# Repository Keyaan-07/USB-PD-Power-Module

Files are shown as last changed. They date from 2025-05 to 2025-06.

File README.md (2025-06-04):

# USB-PD-Power-Supply
Sometimes it happens that when playing with electronics, we need more than 5V or 9V. USB PD Power Supply Solves this issue.  
By using USB PD Protocol, it can negotiate more than 5V from the USB PD charger. It can give voltage outputs as supported by the PD charger from 5V to 20V and it also supports the new USB PPS protocol which allows us set the voltage according to our own needs. For Example, if some device needs 18V, PPS can do the task and it could supply voltage.  

USB PD Power Supply can use both PD and PPS to cupply voltage. The microcontroller is the OG RP2040, which communications with the AP33772SDKZ USB PD negotiator IC to negotiate voltage levels. The Voltage and max current settings are controllable using the two rotary encoders present on the PCB.  

## How the heck do you assemble this thing?
First of all, you start with the gerber and upload it to your desired pcb manufacturer, I am gonna use [PCB Power](https://pcbpower.com). Now you order the PCB and all the components, and you wait, after they arrive, you cook(assemble) the PCB. Then what you do is that you upload the code and start using, 3D printed case is optional but you could download the files for that too! Flash firmware(firmware to come in a few days) on RP2040 using thonny or other software and boom your [USB-PD-Power-supply](https://github.com/Keyaan-07/USB-PD-Power-Supply/) is ready

## Why I chose to make this Project
I chose to make this project mainly because of the power issues i face. A few days ago, I wanted to power a coil for an electromagnet, i was not able to power it because of power supply from the Power bank (5V) was not enough, so i had the idea of making this because my dad's phone has a USB PD Charger so i could use that charger to power electronics that require higher voltage. That type of a project would be too simple, so i also added two rotary encoders and make a dedicated power supply. 

# Images
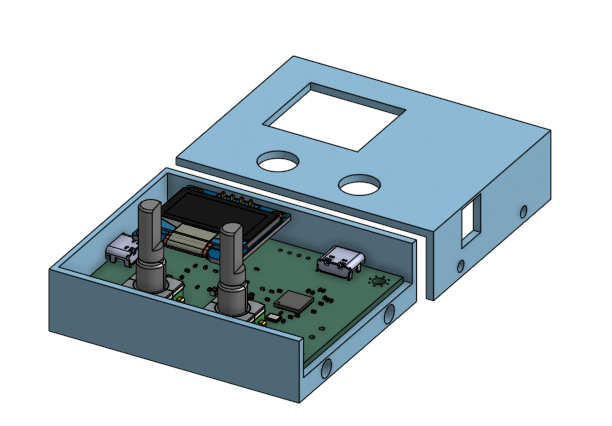
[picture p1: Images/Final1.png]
     
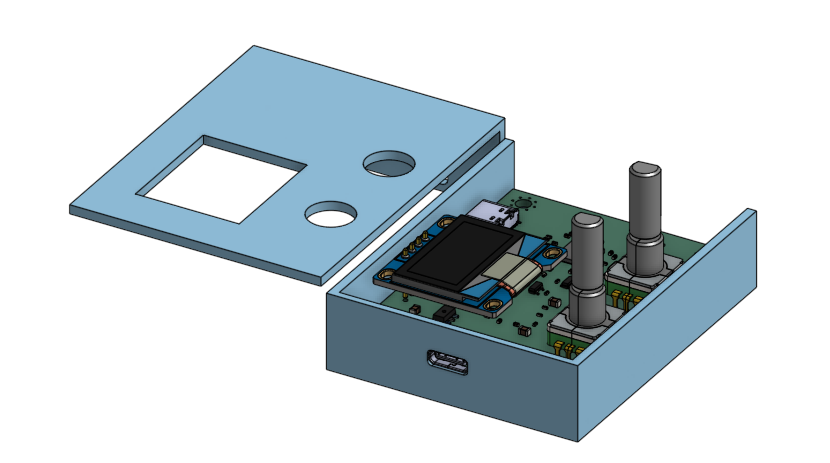
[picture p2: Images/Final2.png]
 
<br>

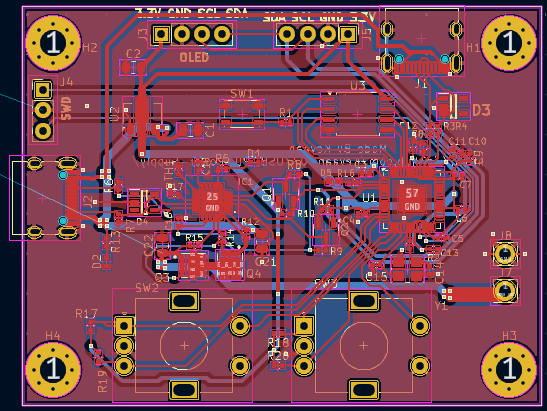
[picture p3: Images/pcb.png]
  

<br>  

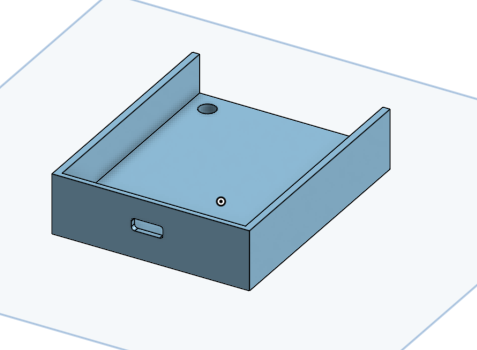
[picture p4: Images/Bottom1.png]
  
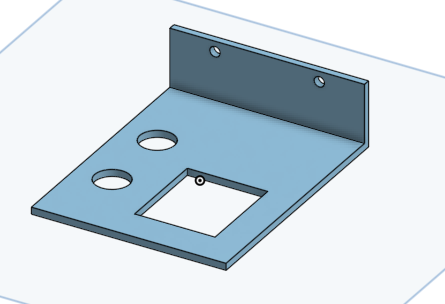
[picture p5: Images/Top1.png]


# BOM - Bill Of All Materials:

| ITEM NAME | ITEM PRICE | FUNCTION | URL |
| --- | --- | --- | --- |
| PCB Manufacturing(5 units) | $29.20 | Main PCB | [https://pcbpower.com](https://pcbpower.com/) |
| PCB Components | $32.12 | All the PCB Components | [https://lcsc.com](https://lcsc.com/) |
| PCB Stencil | $27.25 | Stencil for Assembly of PCB | [https://pcbpower.com](https://pcbpower.com/) |
| OLED and Headers + M3 screws and inserts, Solder Paste | $9.13 | Displays voltage and current levels, assembly body, and solder | https://roboticsdna.in/product/1-3-inch-iic-128x64-oled-display-module-4-pin-blue/ ,  https://roboticsdna.in/product/m3-x-6mm-brass-heat-set-threaded-round-insert-nut-25-pcs/ ,  https://roboticsdna.in/product/m3-6mm-ss-25-pieces/ ,  https://roboticsdna.in/product/2-54mm-1x20-right-angle-female-header-strip-2/ ,   https://roboticsdna.in/product/original-mechanic-30g-solder-paste/ |
| 3d parts | $7.98 | 3d parts | [https://3ding.in/](https://3ding.in/) |
| Total | $105.68 | | |
### Note: There are a few resistors and capacitors, which had very high minimum order quantity(MOQ), about 100 pieces so i had to forcefully include those, which i will be utilising in my next highway projects. And tbh the prices were very less(about $0.002 per piece) so i think it is alright

# PCB Components Breakdown:  

| Id | Designator | MPN | Footprint | DNP | MOQ | Price  | Quantity | Designation | Amount | LCSC Part No. | Supplier and ref |
| -- | --- | --- | --- | --- | --- | --- | --- | --- | --- | --- | --- |
| 1  | Q1,Q2 | BSS138 | SOT-23 | No  | Yes | 0.0571 | 10 | BSS138 | 0.571  | C82045 | https://www.lcsc.com/product-detail/MOSFETs_onsemi-BSS138LT1G_C82045.html?s_z=n_bss138 |
| 2  | C21,C1,C2,C22 | GRM21BR61H106KE43L | C_0805_2012Metric | No  | Yes | 0.0509 | 100 | 10u | 5.09 | C440198 | https://www.lcsc.com/product-detail/Multilayer-Ceramic-Capacitors-MLCC-SMD-SMT_Samsung-Electro-Mechanics-CL21A106KBYQNNE_C2932476.html |
| 3  | R17,R10,R9,R20,R18,R19,R7,R6,R8,R11  | RC0402FR-7W5K1L | R_0402_1005Metric | No  | Yes | 0.0057 | 100 | 5.1k | 0.57 | C278598 | https://www.lcsc.com/product-detail/Chip-Resistor-Surface-Mount_PANASONIC-ERJ2RKF5101X_C278598.html |
| 4  | C14,C15 | GJM1555C1H150FB01D | C_0402_1005Metric | No  | Yes | 0.021  | 20 | 15p | 0.42 | C441742 | https://www.lcsc.com/product-detail/Multilayer-Ceramic-Capacitors-MLCC-SMD-SMT_Murata-Electronics-GJM1555C1H150FB01D_C441742.html |
| 5  | J5 | generic | PinHeader_1x04_P2.54mm_Vertical | Yes | Yes | 0 | 1 | Conn_01x04_Socket_external | 0 | | \- |
| 6  | R2,R1,R5,R16 | ERJPA2F1001X | R_0402_1005Metric | No  | Yes | 0.027  | 20 | 1k | 0.54 | C427241 | https://www.lcsc.com/product-detail/Chip-Resistor-Surface-Mount_PANASONIC-ERJPA2F1001X_C427241.html |
| 7  | Q4,Q3 | AON7672E | TRANS_AONR21307 | No  | No  | 0.7665 | 5 | AON7672E | 3.8325 | C176755 | https://www.lcsc.com/product-detail/MOSFETs_Alpha-Omega-Semicon-AON7262E_C176755.html |
| 8  | C12,C18,C4,C8,C13,C3,C7,C9,C6,C5,C17 | GRM155R61H104JE14D | C_0402_1005Metric | No  | Yes | 0.0074 | 100 | 100n | 0.74 | C426067 | https://www.lcsc.com/product-detail/Multilayer-Ceramic-Capacitors-MLCC-SMD-SMT_Murata-Electronics-GRM155R61H104JE14D_C426067.html |
| 9  | J1 | TYPE-C16PIN | USB_C_Receptacle_XKB_U262-16XN-4BVC11 | No  | Yes | 0.0656 | 10 | USB_C_Receptacle_USB2.0_14P_RP2040 | 0.656  | C393939 | https://www.lcsc.com/product-detail/USB-Connectors_SHOU-HAN-TYPE-C16PIN_C393939.html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 |
| 10 | C10,C11,C16 | GRM155R61H105KE05D | C_0402_1005Metric | No  | Yes | 0.0247 | 20 | 1u | 0.494  | C1518208 | https://www.lcsc.com/product-detail/Multilayer-Ceramic-Capacitors-MLCC-SMD-SMT_Murata-Electronics-GRM155R61H105KE05D_C1518208.html |
| 11 | J4 | generic | PinHeader_1x03_P2.54mm_Vertical | Yes | Yes | 0 | 1 | Conn_01x03_Pin_SWD | 0 | | \- |
| 12 | R13 | RCS040210K0FKED | R_0402_1005Metric | No  | Yes | 0.0278 | 50 | 10k | 1.39 | C3020235 | https://www.lcsc.com/product-detail/Chip-Resistor-Surface-Mount_Vishay-Intertech-RCS040210K0FKED_C3020235.html |
| 13 | D1,D2 | 16-213/GHC-YR1S1N/3T | LED_0402_1005Metric | No  | Yes | 0.0526 | 20 | LED | 1.052  | C2980183 | https://www.lcsc.com/product-detail/LED-Indication-Discrete_Everlight-Elec-16-213-GHC-YR1S1N-3T_C2980183.html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 |
| 14 | U1 | RP2040 | QFN-56-1EP_7x7mm_P0.4mm_EP3.2x3.2mm | No  | No  | 1.1274 | 2 | RP2040 | 2.2548 | C2040 | https://www.lcsc.com/product-detail/Microcontrollers-MCU-MPU-SOC_Raspberry-Pi-RP2040_C2040.html?s_z=n_rp2040 |
| 15 | J2 | TYPE-C16PIN | USB_C_Receptacle_XKB_U262-16XN-4BVC11 | No  | No  | 0.0656 | 0 | USB_C_Receptacle_USB2.0_14P | 0 | C393939 | https://www.lcsc.com/product-detail/USB-Connectors_SHOU-HAN-TYPE-C16PIN_C393939.html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 |
| 16 | Y1 | ABM8-272-T3 | Crystal_SMD_3225-4Pin_3.2x2.5mm | No  | No  | 0.3856 | 2 | Crystal_GND24 | 0.7712 | C20625731 | https://www.lcsc.com/product-detail/Crystals_Abracon-LLC-ABM8-272-T3_C20625731.html?s_z=n_abm8 |
| 17 | D3,D4 | ESDS314DBVR | SOT-23-5 | No  | Yes | 0.2348 | 5 | ESDS314DBVR | 1.174  | C1847859 | https://www.lcsc.com/product-detail/ESD-and-Surge-Protection-TVS-ESD_Texas-Instruments-ESDS314DBVR_C1847859.html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 |
| 18 | TH1 | NCP15XH103F03RC | R_0402_1005Metric | No  | Yes | 0.0104 | 1 | 10k @ 25C | 0.0104 | C209959 | https://www.lcsc.com/product-detail/NTC-Thermistors_TDK-NTCG103JF103FT1_C209959.html |
| 19 | D5 | 16-213/GHC-YR1S1N/3T | LED_0402_1005Metric_Pad0.77x0.64mm_HandSolder  | No  | Yes | 0.0526 | 0 | LED | 0 | C2980183 | https://www.lcsc.com/product-detail/LED-Indication-Discrete_Everlight-Elec-16-213-GHC-YR1S1N-3T_C2980183.html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 |
| 20 | R14 | ERJPA2J100X | R_0402_1005Metric | No  | Yes | 0.0201 | 20 | 10 | 0.402  | C427198 | https://www.lcsc.com/product-detail/Chip-Resistor-Surface-Mount_PANASONIC-ERJPA2J100X_C427198.html |
| 21 | J6 | 6.94108E+11 | BarrelJack_Wuerth_6941xx301002 | Yes | Yes | 0 | 0 | Barrel_Jack | 0 | | |
| 22 | SW3 | EC11E1820402 | RotaryEncoder_Alps_EC11E-Switch_Vertical_H20mm | No  | Yes | 1.548  | 1 | RotaryEncoder_Switch_Current | 1.548  | C361167 | https://www.lcsc.com/product-detail/Rotary-Encoders_ALPSALPINE-EC11E1820402_C361167.html |
| 23 | R4,R3 | ERJ2GEJ270X | R_0402_1005Metric | No  | Yes | 0.0039 | 100 | 27 | 0.39 | C278580 | https://www.lcsc.com/product-detail/Chip-Resistor-Surface-Mount_PANASONIC-ERJ2GEJ270X_C278580.html |
| 24 | IC1 | AP33772DKZ-13 | AP33772SDKZ13FA01 | No  | No  | 1.6472 | 2 | AP33772SDKZ-13-FA01 | 3.2944 | C5244513 | https://www.lcsc.com/product-detail/AC-DC-Controllers-and-Regulators_Diodes-Incorporated-AP33772DKZ-13_C5244513.html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 |
| 25 | SW2 | EC11E1820402 | RotaryEncoder_Alps_EC11E-Switch_Vertical_H20mm | No  | Yes | 1.548  | 1 | RotaryEncoder_Switch_Voltage | 1.548  | C361167 | https://www.lcsc.com/product-detail/Rotary-Encoders_ALPSALPINE-EC11E1820402_C361167.html |
| 26 | U3 | W25Q128JVSIM | SOIC-8_5.23x5.23mm_P1.27mm | No  | Yes | 1.1083 | 5 | W25Q128JVS | 5.5415 | C2613930 | https://www.lcsc.com/product-detail/NOR-FLASH_Winbond-Elec-W25Q128JVSIM_C2613930.html?s_z=n_W25Q128JVS |
| 27 | R12 | PA0402FRL570R005L | R_0402_1005Metric | No  | Yes | 0.0679 | 5 | 5m | 0.3395 | C723468 | https://www.lcsc.com/product-detail/Current-Sense-Resistors-Shunt-Resistors_YAGEO-PA0402FRL570R005L_C723468.html |
| 28 | J3 | generic | PinHeader_1x04_P2.54mm_Vertical | Yes | Yes | 0 | 0 | Conn_01x04_Socket_OLED | 0 | | |
| 29 | U2 | AMS1117S-3.3 | SOT-89-3 | No  | Yes | 0.1057 | 5 | AMS1117s-3.3 | 0.5285 | C917152 | https://www.lcsc.com/product-detail/Voltage-Regulators-Linear-Low-Drop-Out-LDO-Regulators_JSMSEMI-AMS1117S-3-3_C917152.html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 |
| 30 | R15 | ERJPA2J101X | R_0402_1005Metric | No  | Yes | 0.0374 | 20 | 100 | 0.748  | C427204 | https://www.lcsc.com/product-detail/Chip-Resistor-Surface-Mount_PANASONIC-ERJPA2J101X_C427204.html |
| 31 | SW1 | PTS810SJK250SMTRLFS  | SW_SPST_PTS810 | No  | No  | 0.6744 | 2 | SW_Push | 1.3488 | C221896 | https://www.lcsc.com/product-detail/Tactile-Switches_C-K-PTS810SJK250SMTRLFS_C221896.html?s_z=n_C221896 |

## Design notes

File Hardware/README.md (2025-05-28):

# Hardware for USB-PD-Power-supply is in this directory

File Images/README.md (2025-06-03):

# Images for USB-PD-Power-supply are in this directory

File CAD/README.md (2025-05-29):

# What are all the CAD Files?

* **USB_PD_Power_Supply.step** - Main CAD file showing how the project will look.
* **Bottom.stl** - Bottom Plate for 3D Printing
* **Top.stl** - Top Cover Plate for 3D Printing
* **PCB.step** - the CAD model of the PCB.

--------------
# USB_PD_Power_Supply.step



--------------
# Bottom.stl

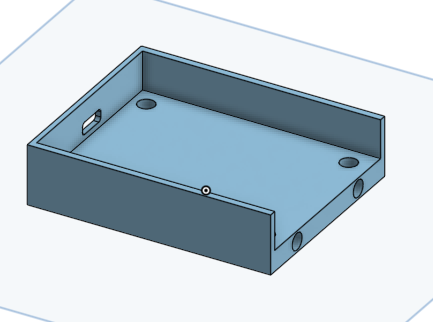
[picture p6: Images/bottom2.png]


--------------

# Top.stl

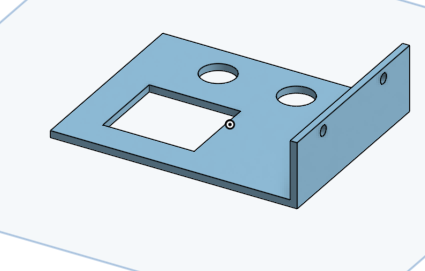
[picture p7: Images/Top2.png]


--------------

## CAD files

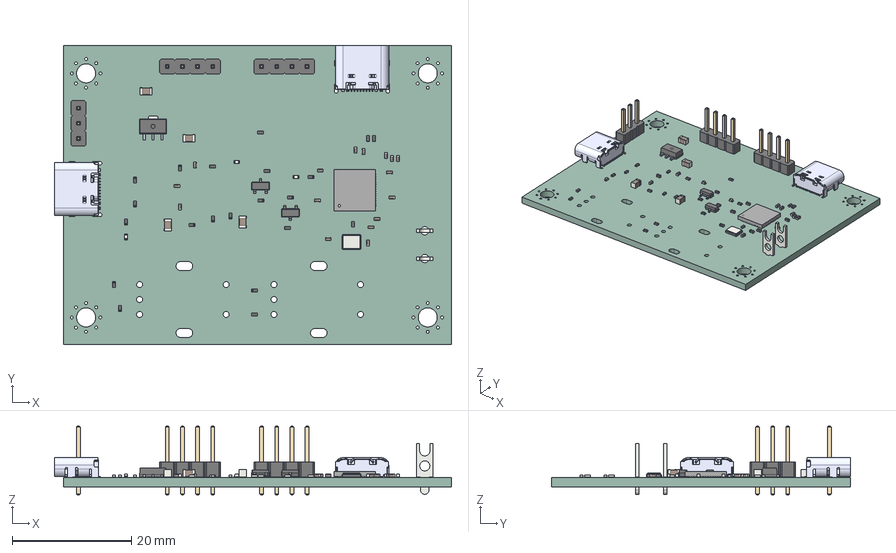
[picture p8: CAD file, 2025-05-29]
CAD/PCB.step
66.5 x 50.0 x 11.5 mm
SOT_23 x 2
C_0805_2012Metric x 4
R_0402_1005Metric x 21
C_0402_1005Metric x 16
PinHeader_1x04_P254mm_Vertical x 2
USB4105-GF-A-060 x 2
PinHeader_1x03_P254mm_Vertical
LED_0402_1005Metric x 3
QFN_56_1EP_7x7mm_P04mm_EP32x32mm
Crystal_SMD_3225-4Pin_3.2x2.5mm
Pin_d1.4mm_L8.5mm_W2.8mm_FlatFork x 2
CQ assembly
power_board_PCB

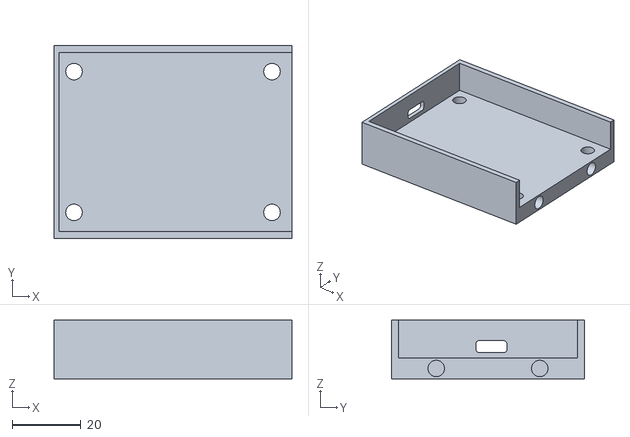
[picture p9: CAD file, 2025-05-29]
CAD/Bottom.stl
69.0 x 56.0 x 17.0

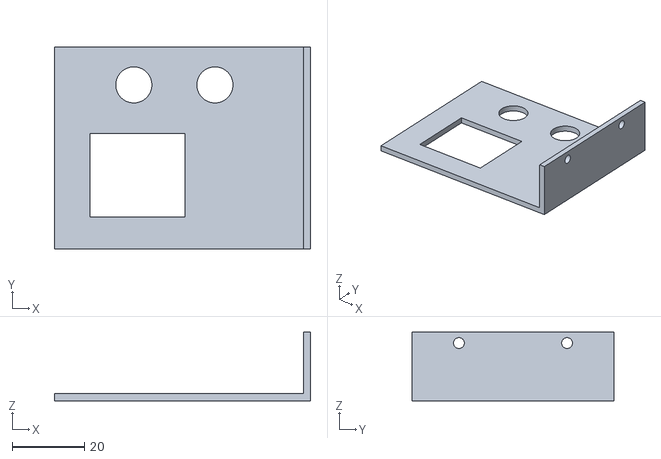
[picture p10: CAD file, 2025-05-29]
CAD/Top.stl
71.0 x 56.0 x 19.0

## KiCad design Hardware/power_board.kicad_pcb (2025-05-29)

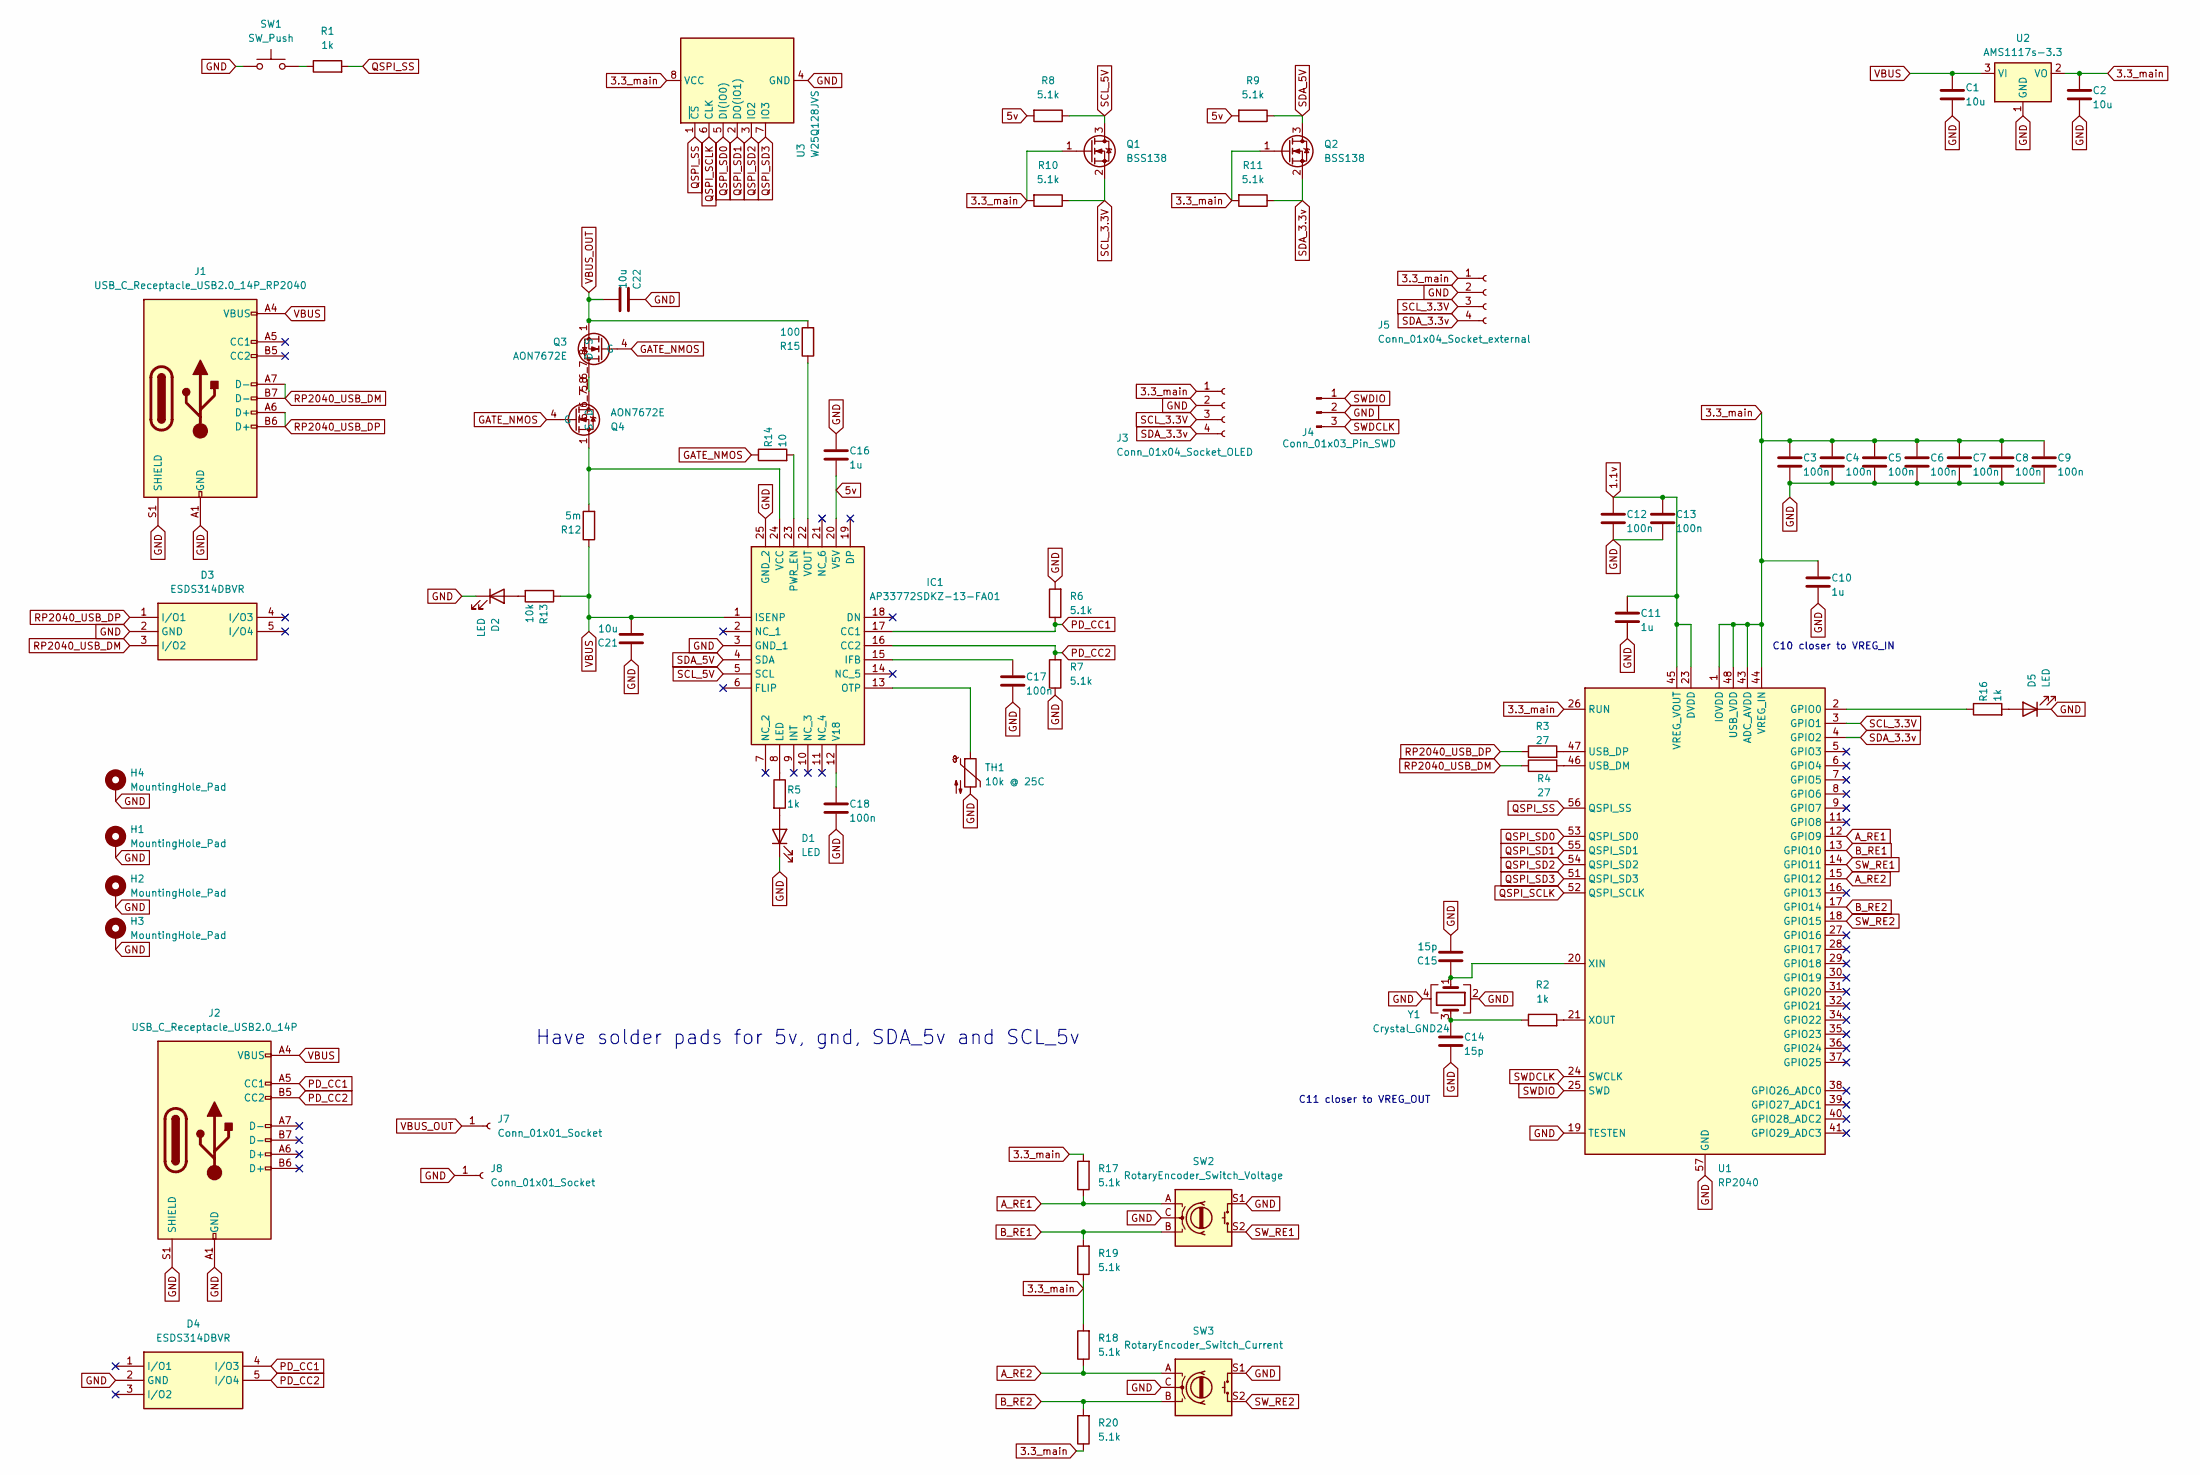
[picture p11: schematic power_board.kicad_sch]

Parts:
C1, C2, C21, C22: 10u; C_0805_2012Metric
C3, C4, C5, C6, C7, C8, C9, C12, C13, C17, C18: 100n; C_0402_1005Metric
C10, C11, C16: 1u; C_0402_1005Metric
C14, C15: 15p; C_0402_1005Metric
D1, D2: LED; LED_0402_1005Metric
D3, D4: ESDS314DBVR; SOT95P280X145-5N; Mouser Part Number 595-ESDS314DBVR
D5: LED; LED_0402_1005Metric_Pad0.77x0.64mm_HandSolder
H1, H2, H3, H4: MountingHole_Pad
IC1: AP33772SDKZ-13-FA01; AP33772SDKZ13FA01; Mouser Part Number 621-P33772SDKZ13FA01
J1: USB_C_Receptacle_USB2.0_14P_RP2040; USB_C_Receptacle_XKB_U262-16XN-4BVC11
J2: USB_C_Receptacle_USB2.0_14P; USB_C_Receptacle_XKB_U262-16XN-4BVC11
J3: Conn_01x04_Socket_OLED; PinHeader_1x04_P2.54mm_Vertical
J4: Conn_01x03_Pin_SWD; PinHeader_1x03_P2.54mm_Vertical
J5: Conn_01x04_Socket_external; PinHeader_1x04_P2.54mm_Vertical
J7, J8: Conn_01x01_Socket; Pin_D1.4mm_L8.5mm_W2.8mm_FlatFork
Q1, Q2: BSS138; SOT-23
Q3, Q4: AON7672E; TRANS_AONR21307
R1, R2, R5, R16: 1k; R_0402_1005Metric
R3, R4: 27; R_0402_1005Metric
R6, R7, R8, R9, R10, R11, R17, R18, R19, R20: 5.1k; R_0402_1005Metric
R12: 5m; R_0402_1005Metric
R13: 10k; R_0402_1005Metric
R14: 10; R_0402_1005Metric
R15: 100; R_0402_1005Metric
SW1: SW_Push; SW_SPST_PTS810
SW2: RotaryEncoder_Switch_Voltage; RotaryEncoder_Alps_EC11E-Switch_Vertical_H20mm
SW3: RotaryEncoder_Switch_Current; RotaryEncoder_Alps_EC11E-Switch_Vertical_H20mm
TH1: 10k @ 25C; R_0402_1005Metric
U1: RP2040; QFN-56-1EP_7x7mm_P0.4mm_EP3.2x3.2mm
U2: AMS1117s-3.3; SOT-89-3
U3: W25Q128JVS; SOIC-8_5.23x5.23mm_P1.27mm
Y1: Crystal_GND24; Crystal_SMD_3225-4Pin_3.2x2.5mm

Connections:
1.1v: C11.2, C12.2, C13.2, U1.23 (DVDD), U1.45 (VREG_VOUT), U1.50 (DVDD)
3.3_main: C2.2, C3.2, C4.2, C5.2, C6.2, C7.2, C8.2, C9.2, C10.2, J3.1, J5.1, Q1.1 (G), Q2.1 (G), R10.2, R11.2, R17.2, R18.2, R19.1, R20.1, U1.1 (IOVDD), U1.10 (IOVDD), U1.22 (IOVDD), U1.26 (RUN), U1.33 (IOVDD), U1.42 (IOVDD), U1.43 (ADC_AVDD), U1.44 (VREG_IN), U1.48 (USB_VDD), U1.49 (IOVDD), U2.2 (VO), U3.8 (VCC)
5v: C16.1, IC1.20 (V5V), R8.2, R9.2
A_RE1: R17.1, SW2.A, U1.12 (GPIO9)
A_RE2: R18.1, SW3.A, U1.15 (GPIO12)
B_RE1: R19.2, SW2.B, U1.13 (GPIO10)
B_RE2: R20.2, SW3.B, U1.17 (GPIO14)
GATE_NMOS: Q3.4 (G), Q4.4 (G), R14.1
GND: C1.1, C2.1, C3.1, C4.1, C5.1, C6.1, C7.1, C8.1, C9.1, C10.1, C11.1, C12.1, C13.1, C14.1, C15.1, C16.2, C17.1, C18.1, C21.2, C22.2, D1.1 (K), D2.1 (K), D3.2 (GND), D4.2 (GND), D5.1 (K), H1.1, H2.1, H3.1, H4.1, IC1.3 (GND_1), IC1.25 (GND_2), J1.A1 (GND), J1.A12 (GND), J1.B1 (GND), J1.B12 (GND), J1.S1 (SHIELD), J2.A1 (GND), J2.A12 (GND), J2.B1 (GND), J2.B12 (GND), J2.S1 (SHIELD), J3.2, J4.2, J5.2, J8.1, R6.2, R7.1, SW1.1, SW2.C, SW2.S1, SW3.C, SW3.S1, TH1.2, U1.19 (TESTEN), U1.57 (GND), U2.1 (GND), U3.4 (GND), Y1.2, Y1.4
unnamed: C14.2, R2.1, Y1.3
unnamed: D1.2 (A), R5.2
unnamed: D2.2 (A), R13.2
unnamed: D5.2 (A), R16.2
unnamed: C17.2, IC1.15 (IFB)
unnamed: IC1.8 (LED), R5.1
unnamed: IC1.13 (OTP), TH1.1
unnamed: IC1.23 (PWR_EN), R14.2
unnamed: C18.2, IC1.12 (V18)
unnamed: IC1.24 (VCC), Q4.1 (S), R12.2
unnamed: IC1.22 (VOUT), R15.1
unnamed: Q3.5_6_7_8 (D), Q4.5_6_7_8 (D)
unnamed: R1.1, SW1.2
unnamed: R16.1, U1.2 (GPIO0)
unnamed: R4.2, U1.46 (USB_DM)
unnamed: R3.2, U1.47 (USB_DP)
unnamed: C15.2, U1.20 (XIN), Y1.1
unnamed: R2.2, U1.21 (XOUT)
PD_CC1: D4.4 (I/O3), IC1.17 (CC1), J2.A5 (CC1), R6.1
PD_CC2: D4.5 (I/O4), IC1.16 (CC2), J2.B5 (CC2), R7.2
QSPI_SCLK: U1.52 (QSPI_SCLK), U3.6 (CLK)
QSPI_SD0: U1.53 (QSPI_SD0), U3.5 (DI(IO0))
QSPI_SD1: U1.55 (QSPI_SD1), U3.2 (DO(IO1))
QSPI_SD2: U1.54 (QSPI_SD2), U3.3 (IO2)
QSPI_SD3: U1.51 (QSPI_SD3), U3.7 (IO3)
QSPI_SS: R1.2, U1.56 (QSPI_SS), U3.1 (~CS)
RP2040_USB_DM: D3.3 (I/O2), J1.A7 (D-), J1.B7 (D-), R4.1
RP2040_USB_DP: D3.1 (I/O1), J1.A6 (D+), J1.B6 (D+), R3.1
SCL_3.3V: J3.3, J5.3, Q1.2 (S), R10.1, U1.3 (GPIO1)
SCL_5V: IC1.5 (SCL), Q1.3 (D), R8.1
SDA_3.3v: J3.4, J5.4, Q2.2 (S), R11.1, U1.4 (GPIO2)
SDA_5V: IC1.4 (SDA), Q2.3 (D), R9.1
SWDCLK: J4.3, U1.24 (SWCLK)
SWDIO: J4.1, U1.25 (SWD)
SW_RE1: SW2.S2, U1.14 (GPIO11)
SW_RE2: SW3.S2, U1.18 (GPIO15)
VBUS: C1.2, C21.1, IC1.1 (ISENP), J1.A4 (VBUS), J1.A9 (VBUS), J1.B4 (VBUS), J1.B9 (VBUS), J2.A4 (VBUS), J2.A9 (VBUS), J2.B4 (VBUS), J2.B9 (VBUS), R12.1, R13.1, U2.3 (VI)
VBUS_OUT: C22.1, J7.1, Q3.1 (S), R15.2

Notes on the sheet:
C10 closer to VREG_IN
Have solder pads for 5v, gnd, SDA_5v and SCL_5v
C11 closer to VREG_OUT

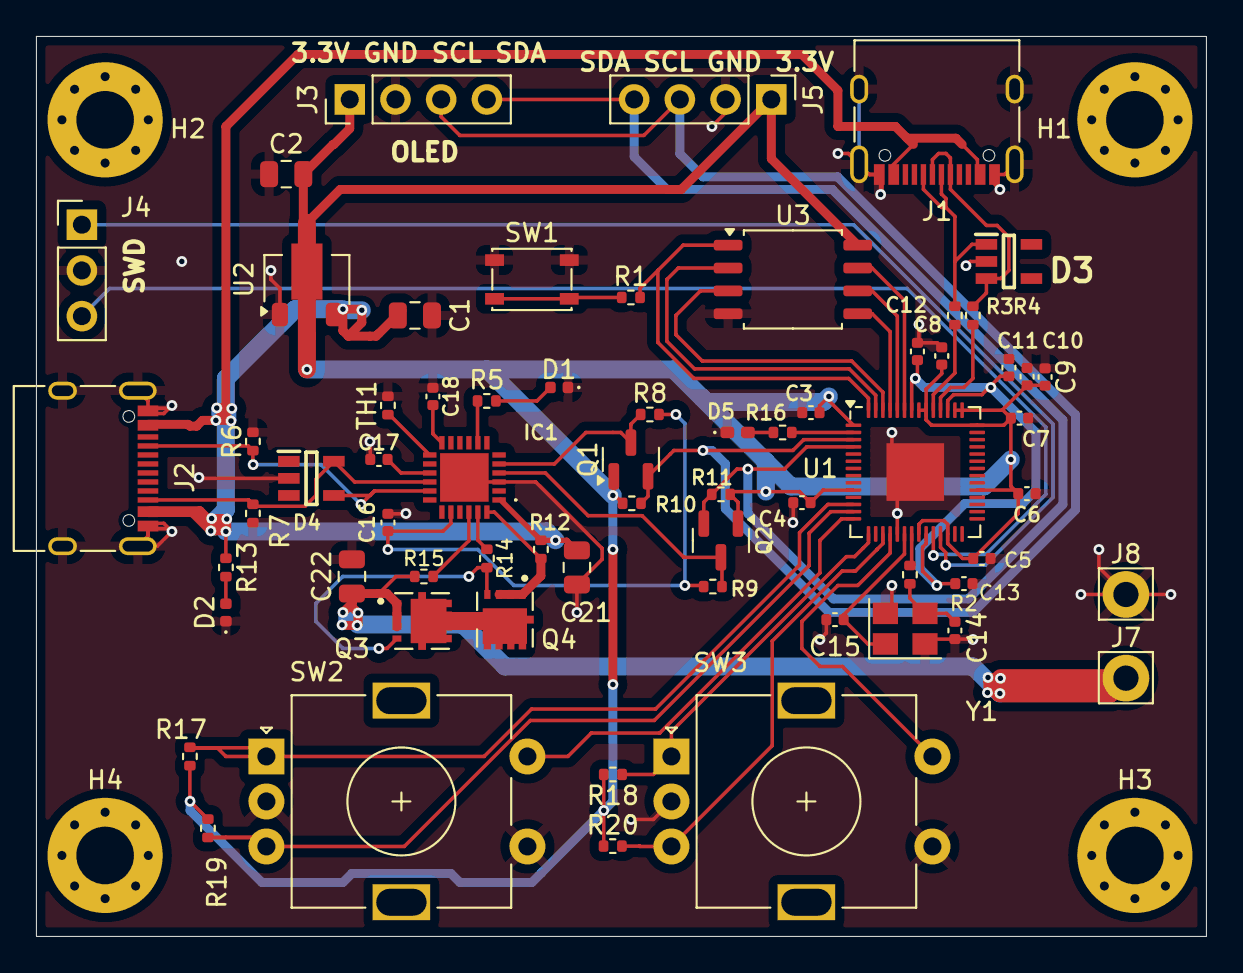
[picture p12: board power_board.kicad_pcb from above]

Board: 2 copper layers, 65.0 x 50.0 mm, 69 parts (0 on the bottom side), 47 nets.

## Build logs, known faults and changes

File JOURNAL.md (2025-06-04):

---
title: "USB PD Power Suply"
author: "Keyaan"
description: "USB-PD Based Power Supply to power your non-5V electronics"
created_at: "2024-05-23"
---
--------------
# Total Time Spent: 14 hours
# Also spent about 3 hours making the BOM and finalising components

# May 23 2025:
Today i will be finding the USB PD negotiation IC. So basically i have the idea of making the smallest(that i can create) power module to power my electronics projects,
when i am prototyping.

okay, found the IC, it is [AP33772SDKZ-13-FA01](https://www.mouser.in/ProductDetail/Diodes-Incorporated/AP33772SDKZ-13-FA01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), and now i have another idea, let's make a variable power supply, which gives variable power supply if PPS is available, or else it gives constant supply @ 5V, 9V, 12V, 15V or 20V.

i think i am gonna use some microcontroller (probably an rp2040) along with an OLED that displays voltage and current, and also rotary encoders/potentiometers, although i haven't decided on that.

### Total Time Spent - 20 Mins

--------------
# May 24 2025:
Today, i made a block diagram by hand, and i selected the [ams1117 3.3v LDO regulator](https://lcsc.com/product-detail/Linear-Voltage-Regulators-LDO_Advanced-Monolithic-Systems-AMS1117-3-3_C6186.html) for the RP2040, but then i came to realise that the max input voltage for ams1117 is 15V, while max voltage with PD is 20V, so i chose another regulator(it is so hard to find a proper regulator). the new regulator now is [AMS1117S-3.3](https://lcsc.com/product-detail/Voltage-Regulators-Linear-Low-Drop-Out-LDO-Regulators_JSMSEMI-AMS1117S-3-3_C917152.html)

Handmade Block Diagram

I have also decided that instead of using EasyEDA this time, i will be using "KICAD - THE DAD OF CIRCUIT DESIGN"(lol). I started working on the schematic. RP2040 is also finalised for now. so 2 USB-C connectors will be on the PCB, one for programming RP2040 and other for **POWER**

Ok, so let me just write out all the finalised parts here:
1. [I2C OLED](https://robu.in/product/4pin-oled-display-module-blue-color/)
2. [Rotary Encoders x2](https://robu.in/product/hongyan-ec11h-7ce15p1zy15f7-rotary-encoder-with-push-button-switch-vertical-plug-in/), [what i chose earlier](https://robu.in/product/4pin-oled-display-module-blue-color/)
3. Microcontroller: [RP2040](https://www.lcsc.com/product-detail/Microcontrollers-MCU-MPU-SOC_Raspberry-Pi-RP2040_C2040.html)
4. [Flash for RP2040](https://lcsc.com/product-detail/NOR-FLASH_Winbond-Elec-W25Q128JVSIQ_C97521.html)
5. USB PD Sink Controller: [AP33772SDKZ-13-FA01](https://www.mouser.in/ProductDetail/Diodes-Incorporated/AP33772SDKZ-13-FA01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)
6. [Push Button](https://lcsc.com/product-detail/Tactile-Switches_C-K-PTS810SJK250SMTRLFS_C221896.html)
7. [Crystal @ 12MHz](https://www.lcsc.com/product-detail/Crystals_Abracon-LLC-ABM8-272-T3_C20625731.html?s_z=n_ABM8-272-T3)

#### Why I chose a 128Mbit chip instead of a smaller one?
I chose a bigger chip rather than the typical 16Mbit because of mainly three reasons:  
    1. the difference in price is about $0.1.  
    2. The RP2040 design guide recommends it.  
    3. I dont know how long is the code gonna be.  

ok, so i have finished with the work for the day, today i completed the RP2040 connections, like the bare minimum connections required, and i also finalised the parts, and tomorrow i will be looking into the connections of the USB-PD controller, and i hope to make a 4 layer PCB, although i will try with 2 layers, if it will be possible.
Schematic done on 24th may

PS: I am changing the rotary encoders as i found out about a new, more popular encoder, the [EC11H](https://robu.in/product/hongyan-ec11h-7ce15p1zy15f7-rotary-encoder-with-push-button-switch-vertical-plug-in/), which is the one that i will be using...  

okay, i had some free time tonight so i worked more on the schematic, i came to realise that i have to LOGIC-SHIFT the I2C communication, so that i dont burn the rp2040, so for logic shifting i found BS138 to be the most common and i went with them. So, for proper logic-shifting, we also need a proper 5V supply, so i chose another LDO regulator😭(it's a pain finding proper regulator). A wise legend once said, choose your components wisely.Btw, i also added a few capacitors to the PD controller.

Things added to schematic:  



If i were to rate the experience using Kicad rather than EasyEDA, i would say that it is good, and you get A LOT of customisability, but EasyEDA is much simple.

### Total Time Spent today - 2 hours 10 mins
--------------
# May 25 2025:
Another New day, another new schematic making sesh...
Today i will likely complete the schematic

So i have added the rotary encoders in the schematic, and i also added ESD protection on the USB-C ports. worked on the schematic too, and i had a bit of issue with the PD controller, what happened was that there were two voltage pins, VCC and VOUT, and i wasn't sure what to cnnect to what, but now it is fixed, thanks to the application circuit. so the plan is, today i finish the schematic, i start with the PCB at night, and by tomorrow night i start with the cad, and i apply by day after tomorrow night, let's  see if i can apply by May 27 night, after that i will start with the code for it.  
#### Yay! the schematic is done!!  





Ok, it's evening now, and i completed all the work of assigning footprints to symbols, now i can finally start with pcb designing

Hell Yeah! Most of the placement on my PCB is like done, and tomorrow i will start with the routing and finish it ASAP.  
  
  
Haha, i will add 3d models tomorrow.  
This is the Design till now, i've tried to keep it as small as possible(50mmx70mm) and i will reduce the size even more if needed, but i haven't yet found connectors. People on slack recommened me XT60 connector, but i am not sure what am i gonna use.  
Maybe i can integrate multiple kinds of connectors, but this is for tomorrow, i am really really tired today

### Total time spent: 6 hours
--------------
# May 26 2025:
Yup, i started the PCB routing, i added 4 M3 Mounting holes too, here is the current progress:  


#### Time spent this session: 1 hour 45 mins
### Time Spent Today: 1 hour 45 mins
--------------
# May 27 2025
Today was the day i was supposed to complete my project, it is ofcourse delayed, but i will try to complete by tomorrow, i completed the pcb today, got a few errors to deal with:  
  
All the errors are the same, just for different components.
Here is the finished PCB:  


Here is the CAD file i started tonight:  
  
(I spent 5 mins only on the CAD)  

### Time Spent Today: 1 hour 30 mins
--------------
# May 28 2025
Done with the PCB, rmeoved all the thermal errors by using a bunch of vias and got 0 errors and warnings! I also shifted the barrel jack to the right by 2mm so that it would not be a problem in 3d printed part... Now Working on the 3D Model
#### Time Spent this session: 20 mins
 Completed the CAD, here are the final images:  
   
 CAD:  
     
 

PCB:  
  
  

### Time Spent this session: 1 hour 45 mins

Now time to work on other things like writing README.md and writing total time on top and writing BOM and all that

# May 29 2025
Shit, i cant find any DC barrel jack connectors on LCSC and i made a mistake selecting the footprint of the regulator ic, so i got to change some stuff up😭  
Finally:  
Final PCB

# time spent today: 30 mins
